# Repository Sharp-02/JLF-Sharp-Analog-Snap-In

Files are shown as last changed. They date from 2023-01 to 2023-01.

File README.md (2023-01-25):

# Sharp Analog Snap-In (SASI) Mod
### A full analog addition to the Sanwa JLF that replaces your lever's restrictor gate


# Features
- Full analog range from 0V-3.3V for Joystick X and Y
- Drop-in modification for easy installation
- Designed for fully 3D-Printable mechanical assembly
- Maintains original digital signals for both D-Pad and 
- Low profile and doesn't add much height to the stock joystick assembly
- No potentiometers that wear down with usage
- Linear hall effect sensors with sliding magnet mounts
- "Snapback Filtering" capability
- Custom PCB for footprint and consistent reproduction

# Overview
The Sharp Analog Snap-In, or SASI (pronounced "sassy"), adds analog functionality to the pre-existing Sanwa JLF lever. 

This mod was made primarily to play Smash Bros. on a fightstick. It is a component of an analog fightstick.

By measuring the position of the bottom of the lever, it outputs an analog voltage that can connect to most controller boards (boards that have 3.3V logic). 
To do this, the mod mounts magnets that move with the lever, and measures their location through a linear hall-effect sensor. 
This sensor outputs a voltage, which is amplified to match the 0V-3.3V range that most controllers use. 
*This does not use a microcontroller, and cannot be programmed.* 
A lack of programmability is desireable for cases such as tournament use or for simple implementations. 
By having no programming, the output is a direct relationship to the lever position and cannot "correct" itself automatically.
*For it's main purpose, this is just a lever that can replace a thumbstick/analog input.*

# Analog vs. Digital

The SASI mod snaps onto a Sanwa JLF lever. The Sanwa JLF is a very widespread and easily obtainable lever. 
However, this lever, like most others on the market, has only digital inputs. A digital input has only on or off states, nothing in between. 
In practice, this means that you can press up, down, left, and right, but you can't lightly move in one direction. 
This works well for most fighting games, as there is no change in movement speed depending on how far you press in a direction.

An analog system, on the other hand, does not have only discreet on/off states. 
Rather, you are able to be somewhere in the middle, maybe at 70% the maximum, or 22%, or whatever resolution your device gives you. 
For gaming, the SASI mod would allow you to gently move into a direction, or move at a specific angle.
You would want this light movement functionality in games such as Super Smash Brothers, 
where analog inputs are needed for different inputs and actions, or Mario Kart, where adjustments might be made with very slight movements.

What this is NOT is an analog-to-digital system like the programmable Magenta lever by Paradise Arcade. 
The Magenta lever acts by measuring an analog distance and setting a threshold upon which to count as a "button press". 
This mod, though it does not remove button press functionality, does not output any button press commands.

# Assembly and Installation
The mod is implemented by replacing the restrictor gate of the Sanwa JLF with a custom restrictor gate assembly. 
In this assembly are the base custom restrictor gate replacement, control PCB with the hall-effect sensors, 
slider arms that follow the lever's position, and the shroud to maintain the motion of the slider arms.

## Electronics
Components:

- DRV5053 Linear Hall Effect Sensors (x2)
- TLC2254 Op-Amp (x1)
- 0603 SMD resistors (22k, 47k, and 100)
- THT Trimpots (1k and 50k)
- 90 degree JST PH 4 position connector
- PCB

### PCB:
The PCB (printed circuit board) mounts and connects all the electronics. 
It is shaped after the Sanwa JLF's PCB that mounts the digital switches. 
On the PCB are the hall-effect sensors that measure the lever position, 
as well as potentiometers that determine the offset and voltage swing of the individual X and Y axes. 
All references to the **"front"** of the PCB refer to the side with arrows and values printed on, 
and is the side that most components solder to. The **"rear"** is the opposite side, with only the op-amp soldered on it. 
Inspect the PCB for any manufacturing errors that affect the copper traces near the outer edges and inner ring. 
Note that the PCB has SMD solder connections on both its front and rear.

Left: Front side of PCB; Right: Rear side of PCB

### Hall-Effect Sensors:
This modification uses DRV5053CAQLPG Linear Hall Effect Sensors to measure position of the lever. 

The purpose of the hall effect sensor is to measure the strength of the magnetic field and output a signal. 
The "hall effect" described makes use of the property of flowing electrons to have an induced force in the presence of a magnetic field, 
otherwise known as the Lorentz Force. The hall effect is an extrapolation of this force, wherein a current within a magnetic field 
(measured in Tesla) will "bend" as a funcion of the Lorentz force and accumulate charges in a conductor or semiconductor.

There are primarily two types of hall effect sensors seen in use today- the Hall Switch, and the Linear Hall Sensor. 
The SASI mod uses a Linear Hall Effect sensor, which outputs a voltage relative to the strength of the magnetic field. 
The sensor used is the DRV5053 whose pins when viewed from the front, from left to right, are: Vcc, GND, and Vout. 
The "CA" designation indicates that the sensor outputs a voltage of +23mV/mT. 
The "Q" designation denotes that the temperature range of the sensor is from -40 C to 125 C. 
The "LPG" designation indicates the TO-92 package type.

The DRV5053 sensors used are in a TO-92  package (through hole), ***not*** the SOT-23 package (surface mount). 
These sensors must be soldered on facing the arrows on the PCB. Once soldered, 
the outstanding legs on the opposite side of the PCB must be trimmed flush. 

As the magnet moves along the arrows in front of the sensor, the magnetic field either grows or lessens, 
depending on which pole is approaching the sensor. This means that, as the magnets are moved by the stick, 
the sensor will output a voltage depending on the position of the magnet. 
In testing, the sensor outputs a range from ~1.2V to ~2.2V. [^PCBTest]

[^PCBTest]:The PCB assembly can be tested independent of the full assembly with only a magnet. 
Orient the magnet's north and south poles along the arrow outlined in front of the sensor under testing. 
The output voltage can be measured and compared to the expected range (typically 0V - 3.3V).

### Op-Amp:
The build is tested on and utilizes the TLC2254 Op-Amp (SMD). 
This is a rail-to-rail operational amplifier and is the recommended Op-Amp to use for this mod. 

The op-amp serves the purpose of amplifying the voltage from the hall effect sensor and 
applying an offset through the trimpots as outlined below. Other op-amps *may* work, but are not guaranteed to. 

The op-amp is capable of applying a "gain" to an input voltage, which can be summarized as a direct multiplication. 
For example, a gain of 2 multiplies the input voltage by 2, and a gain of 4.3 multiplies the input voltage by 4.3. 
The SASI uses the op-amp to multiply the sensor voltage (range of ~1V) to match the voltage range expected 
by most controllers and controller boards (3.3V). This gain is altered by the relationship of resistors between 
the op-amps voltage output, voltage input, and ground. On the SASI mod, this can be tuned by turning the GAIN potetionmeters.

The op-amp is also capable of applying an "offset" to an input voltage, 
or an addition/subtraction of voltage level. As the hall-effect sensors will not output voltages starting at 0V, 
a "negative offset" must be applied to the sensor's voltage such that the final output voltage is reduced with 
the lowest output voltage of the mod being 0V. This is tuned by the OFFSET/OFF potentiometers.

The circuit below shows the diagram by which these functions can be performed. Each triangle is an amplifier. 
The TLC2254 Op-Amp contains four amplifier within its IC package.



What the op-amp ***does not do*** is read the input voltage and determine an output voltage or signal like a microcontroller would. 
Op-amps are not "programmable" in the traditional sense that microcontrollers are. 
Microcontrollers are capable of more complex interpretations of data, and can perform operations that allow for perfect inputs and timing. 
Because the op-amp works purely off the analog voltages and circuit design, it cannot be exploited in this manner.



The picture above shows the op-amps capability to amplify the blue signal and shift it up such that a 1V - 2V voltage range becomes a 0V - 3.4V voltage range.

### Trimpots:
The trimmer potentiometers, or trimpots, are a type of potentiometer that often come with multi-turn capability at varying levels of precision. 
Potentiometers are used as a variable resistor, or as a way to connect in the "middle" of a resistor. 
These properties are utilized in the op-amp circuit shown above.



These trimpots are used to alter the gain (YPOTGAIN, XPOTGAIN) and the offset (YPOTOFF, XPOTOFF) of the output voltage, 
and are labeled as such. The gain potentiometers adjust how much movement is required to register as a certain position. 
**This potentiometer has a value of 50k**. Adjust this potentiometer if the controller cannot register full motions across the X or the Y axis. 
The offest potentiometers adjust the center point of the output voltage. **This potentiometer has a value of 10k**. 
If the joystick center drifts off center *or* if the controller can register full motion in one direction but not the opposite 
(example: 100% left to 80% right), adjust this potentiometer for the required axis. Once soldered, trim the legs below flush to the PCB.

### Resistor Network:
All resistors used are 0603 SMD resistors (6mil x 3mil Surface Mount Device). 
Most of the resistors serve the purpose of setting baselines for the offset and gain on the circuit shown above. 
You will need 22k, 47k, and 100 ohm resistors.

### Snapback Filtering:
"Snapback" is a mechanical issue of the spring returning the lever *past* the centerpoint
 enough for a controller or game to register a return to neutral as an opposite direction input. 
This can be remedied through installation of a capacitor to ground, or low pass filter, 
which can reduce the signal of a sharp signal present in snapback. 

There are two locations (top and bottom) dedicated to a "snapback filtering" circuit. 
The 100 ohm resistor is integrated into this circuit. 
The remaining component is a capacitor *whose value is specific to your setup*. Most sticks will not need filtering on their SASI.

### Connector:
The JST PH connector ***is a 2.0mm pitch, not the US standard 2.54mm pitch***. 
This connector *must* be a 90 degree connector and must face out and away from the center of the PCB. 
From the front of the PCB, with the connector oriented to the right, the connector pins are as follows: 
[V+ (top), GND, Signal Y, Signal X (bottom)]. Once soldered in, trim the legs of the connector flush to the PCB.



## Mechanical Components and 3D Printing
The mechanical housing and components are designed for and around additive manufacturing processes, 
most specifically to consumer grade FDM 3D printers. Designs for machined components for low friction 
polyamide and acetate materials are planned for the future.

### Components: 

- Restrictor Gate Replacement (printed)
- Slider Arms (x2, printed)
- Linear Guide/"Hat" (printed)
- 1/8" x 1/8" x 1/2" bar magnet (x2)
- 12mm M3 screws (x4)

### Printed Part Material:
All printed parts are recommended to be printed in Nylon. All parts will undergo a sliding/rubbing motion, 
and any friction will result in less ideal movements of the lever. 
If resin printing is available, it is a good alternative. The assembly works fine with PLA/ABS as well, 
but may require more post processing and frequent application of a dry lubricant.

### Restrictor Gate Replacement:
The restrictor gate replacement is the base of the SASI. 
It houses the PCB, mounts onto the JLF, and acts as it's own restrictor gate. 
The restrictor gate's shape alters the movement of the stick and limits the shape that it can move along. 
For example, Gamecube Controllers have an *octagonal gate*, whereas the Pro Controller and Xbox Controllers have a *circle gate*. 



Which you use is simply a matter of preference. The files contain multiple gate shapes to be used. 
There are no notches in the available files [^notches] 

[^notches]: Notches are a controller modification seen in the Super Smash Brothers Melee community that allows for more specific angles to be placed in along the gate. For those interested in implementing controller notches, it may be more difficult to let the stick "lock" into a notch, as the shaft is wide and has a long area that it can slide along. 

### Slider Arms:
The Slider Arms serve the function of holding the magnets that the hall effect sensors read and, 
at the same time, wrap around the Sanwa JLF lever such that motions in the lever result in motions of the magnets. 
They feature a slot in the center into which the ***actuator*** of the lever fits into.

> picture of one slider arm on lever ; gif of sliding single arm

The lever may slide along the axis the slot opens, but the lever moves the whole part in the axis of the arms.

Two slider arms must be printed ***as mirrors of one another***. This allows them to overlap in the center. 
The 3D slider arm files given come with multiple variations. These variations are as follows:
- +BRIM- Designed with custom brims to prevent/limit warping during manufacturing on small arm sections
- +EXPANDED- Designed for materials that shrink when cooling, with an expanded center slot
- +MACHINABLE- Designed for top-down CNC machining, replacing the magnet cavity with a magnet cradle

These sliders may require post processing, as any imperfections and bumps on the surface can lead to friction and binding in the slider guide. 
This should be done with sandpaper or careful filing to flatten the sides of the slider arms.

In ***only one side of each arm***, insert a magnet and push it until the magnet cannot go any further. 
When testing, you may find that the magnet direction must be flipped. Keep this in mind before pushing in too tight or 
if no tools are available to extract the magnet from the arm (i.e. another stronger magnet). ***TEST THIS BEFORE ASSEMBLY***.
If printing in Nylon or another warp-prone material, use the Slider Arm with Brim file, which limits the warping on the small arms.

### Linear Guide:
The Linear Guide, also called the "hat", mounts above the PCB and prevents the slider arms from having any rotational motion.
The guide restricts arm movement to having only single axis motion.
The hat allows for two independent slider arms to transfer the lever angle into their own linear axis of movement.

## Assembly and Installation

Assembly and installation of the SASI mod is fairly straightforward. Very little modification to the JLF lever is required. 
Components stack on top of one another and do not require precise placement of any parts.

#### Steps:
1. Soldering and Electronics
2. Restrictor Gate and Trimming
3. Arm and Guide Hat
4. Tuning and Testing

### Step 1- Soldering and Electronics
#### 1.1- Soldering Front Components
This section is on soldering the front face of the PCB.

The front of the PCB has multiple surface mount device pads (SMDs) for resistors. Start by "tinning" every **square** pad. 
This is done by heating the pad with an iron and then applying a very small amount of solder to the pad. 
To solder a resistor in place, first identify the two solder pads that correspond to a single resistor placement. 
Prepare an 0603 SMD resistor of the proper value with metal tweezers onto the PCB, near but not on the pads, with the dark/labeled side facing up. 
Re-melt the solder on the set of pads you are soldering to by placing the iron's tip in-between them. 
Gently push the resistor into the melted solder until the resistor is in place. 
Hold the resistors in place as you remove the iron. 
Repeat this process for every resistor.

Next, it is best to solder the JST-PH connector.
Insert the connector with the connection port facing outward and away from the center.
Flip the PCB and hold or place the connector such that a solder can be performed on the rear side.
Solder the pins down, making sure that the connector is solidly in place and not tilted.

After this, solder the trimmer potentiometers.
Take care that each resistor put in is the correct value. 
Bend the legs below such that the trimpots will not move, and flip the board upside-down.
Solder each leg to the through hole.
Trim the legs flush to the bottom of the PCB.

For soldering the hall effect sensors, a similar approach can be taken to that of the potentiometers.
Make sure to mound the hall effect sensors such that the small side faces towards the arrow near it.
Insert the hall effect sensor *all the way*. When inserted, there should only be ~1mm of the legs above the PCB.
Once again, bend the legs below so that the hall effect sensor does not move and solder them in place.

*If you need to solder a capacitor*, perform the same steps as the hall effect sensor soldering.
This, however, is not a snapback elimination guide. 
The process to analyze snapback, though, is the same as with a thumbstick.

#### 1.2 Soldering Rear Component

On the back of the lever are the op-amp pads. The TLC2254 op-amp is the only op amp used, and is the only component on the back of the PCB.
Observe and make note of the small half-circle mark at the top of the outline.
The op-amp component will have a marking on one of its sides. This marking can be a divot, dot, or line.

  

Start by tinning the solder pads in a similar way to the SMD resistors outlined above.
Do not let any of the solder bridge from pad to pad. There should be very little solder on each pad.
Use tweezers to position the op-amp such that each leg is over every pad.
Remelt one corner pad with the iron and gently press the op-amp into place.
Let the corner pad cool, and then repeat the process with the opposite corner pad.
If you are unhappy with the positioning, adjust the two corners until you are satisfied.
Remelt the solder at each solder pad, letting it flow and cover the leg it is on.
The time at each leg should be minimal, and should not take a long time.

#### 1.3 Making a connector

To make a connector to the PCB, prepare four wires of equal length.
The recommended wire and gauge to use is 30AWG stranded wire.
This allows for flexing and movement of the wires with less wear.
Strip one end of each wire and crimp a female JST-PH connector onto the end.
Make sure the inner crimp clamps onto the stripped wire and the outer crimp clamps down the silicone sheathing.
Insert this wire into a female JST-PH connector. 
Repeat this process with the other three wires.

### Step 2- Restrictor Gate and Trimming
#### 2.1 Gate Replacement and Trimming
Remove the original restrictor gate from the Sanwa JLF. This is typically a clear part.
Snap on the SASI Restrictor Gate Replacement.
Mark the oval protrusions at the height of the restrictor gate replacement.
Remove the Restrictor Gate Replacement and cut/trim the oval protrusions at the mark.
**THIS STEP IS CRUCIAL:**
Attach the Gate Replacement and *verify that the oval parts are flush or below the surface of the replacement gate.*

#### 2.2 Replacing the Gate pt. 2
When viewing the bottom of the JLF, ensure that the 5 pins from the JLF's microswitch board face outward from the top right of the board.

The orientation of the restrictor gate is crucial. Identify the eccentric rectangular hole in the restrictor gate.
Make sure that this hole is on the ***left*** side of the JLF, opposite from the 5 pins.

From here, place the soldered PCB into the SASI Restrictor Gate Replacement. 
The op-amp should be facing down and will fit into the rectangular hole, 
while the 4-pin connector faces in the same direction as the JLF's 5 pin connector.

### Step 3- Arm and Slider Guide/"Hat"
#### 3.1 Post Processing
Due to the motions taken by 3D printers, some corners and edges may "blob" outwards and create a wavy surface.
Take each slider arm and sand or file the sides of the arms such that they are straight and smooth.
Observe if the same must be done for the Slider Guide. If similar blobs or wavy patterns are seen, file and sand until smooth.
Do not over-sand, as the looser this tolerance is the less precision there will be from the SASI mod.

#### 3.2 Magnet Insertion
On each arm, identify the hole that will be snug to the bar magnet, but not too tight to insert/extract.
The ability to extract is crucial, as mistakes may be made that require removal of the magnet.
Once identified, insert the magnet fully, but ***do not seal the hole***.

#### 3.3 Slider Testing
Orient the arms on the PCB such that the magnets are in front of the two hall effect sensors.
Gently place the Slider Guide over the slider arms, letting the slider arms slot into the slider guide. 
Remove the Slider Guide and Slider Arms together and move the arms individually to see if there are any binding areas.
If there is no binding and low friction, you are ready for the next step.
If there is binding, maintain the orientation of the arms, but move the slider guide to a new angle until you find the smoothest motion.

#### 3.4 Final Assembly
Replace the SASI Slider Guide and Arms over the PCB and around the lever.
Pinch down firmly at each corner and screw in an M3 screw. Repeat this at every corner.
Finally, feel if the stick is smooth from above. If it is not, return to previous steps to reduce binding.

### Step 4- Tuning and Testing
Once assembled, connect the analog X and analog Y outputs from the stick to the board you are using, alongside the ground and 3.3V connection. 
The connection method varies from board to board. Check with the board manufacturer for the recommended connection method to analog stick inputs.

It is recommended to test the stick without installing it in a panel, so that changes can be easily made.

This can be tested either through a joystick viewer found online or in software, 
or through an oscilloscope by measuring the voltage output. The process remains the same.

Only test one axis at a time. Start by moving the stick fully in one direction, then fully in the other.
If the stick shows that it is moving in reverse, extract the magnet under testing, reverse its orientation, and test again.

Next, make note of two different parameters. The first to observe is the "center point" of the output.
On a joystick tester, it is as simple as checking if the joystick rests at the middle of the axis you are testing.
On an oscilloscope, the "middle" is a level of 1.67V (or 2.5V if you reference a 5V supply). 
If the joystick isn't centered, turn the axis offset potentiometer (right side)such that the signal becomes centered.

Then, once again, move the joystick all the way in both directions of the axis you are testing. 
If the joystick does not reach the maximum, hold the joystick at the maximum and turn the axis gain potentiometer until it reaches it's maximum. 
Once this threshold is hit, hold the joystick in the opposite direction and observe if it reaches the opposite maximum. 
If it does, still read the next paragraph. If it does not, release the joystick and repeat the steps of the previous paragraph.

This paragraph addresses the "outer deadzone", or the range at which the maximum is reached.
Some may prefer that the maximum is reached only at the gate, while some may prefer that the maximum is reached before then.
Treat this section as a sensitivity section.
Start by identifying what your preference is.
Then, ***slowly*** move the stick, observing both the physical stick position ***and*** the software stick position.
If you are not at the measured position that you want, turn the gain potentiometer such that the stick moves in the direction of the desired position.
During this process, constantly check if the joystick's resting position is truly the center of the axis.

After all this, repeat the tuning process on the second axis.

The final and most important step for testing is 
### Play a game!!!
Boot up Dolphin and play some Melee, or see how the joystick feels in Rocket League. Whatever you made this stick for, use it!
This is the truest test you can find, and will very quickly identify any problems you have with the SASI JLF mod.

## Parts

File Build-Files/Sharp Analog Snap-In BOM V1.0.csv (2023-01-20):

Part Name | Part Number | Description | Value | Size | Quantity | Cost Per | Shipping Estimate | Cost Sum | Total Sum | Part Link | Section Sum
Electronics
22k Resistor |  | 0603 SMD | 22k | 0603 | 2 | $0.10 |  | $0.20 | $0.20 |  | $19.50
47k Resistor |  | 0603 SMD | 47k | 0603 | 2 | $0.10 |  | $0.20 | $0.20
100 Resistor |  | 0603 SMD | 100 | 0603 | 2 | $0.10 |  | $0.20 | $0.20
1k Trimpot |  | 3 Pin Trimpot, 10mil pitch | 1k | RTRIMT93YA | 2 | $1.25 |  | $2.50 | $2.50 | https://www.digikey.com/en/products/detail/bourns-inc/PV36W103C01B00/666502
50k Trimpot |  | 3 Pin Trimpot, 10mil pitch | 50k | RTRIMT93YA | 2 | $1.25 |  | $2.50 | $2.50 | https://www.digikey.com/en/products/detail/bourns-inc/PV36W103C01B00/666502
Hall Effect Sensor | DRV5053CAQLPG | Linear Hall Sensor- Through Hole |  | TO-92 | 2 | $1.50 |  | $3.00 | $3.00 | https://www.digikey.com/en/products/detail/texas-instruments/TLC2254CDR/276943
R2R Op-Amp | TLC2254CDR | Rail to Rail Quad Op Amp |  | SOIC-14 | 1 | $3.00 | $2.00 | $3.00 | $5.00 | https://www.digikey.com/en/products/detail/texas-instruments/DRV5053CAQLPGM/5177930
PCB |  | Custom Built PCB |  |  | 1 | $2.00 | $2.00 | $2.00 | $4.00
JST-PH Connector |  | JST-PH 4 Pin, 90 Degrees | 90 Deg | PH | 1 | $0.90 | $0.50 | $0.90 | $1.40
Wires |  | 30 AWG Stranded |  | 12 in. | 4 |  | $0.50 | $0.00 | $0.50
Mechanical Components
Bar Magnet | B228 | K&J Magnetics; Length Magnetized | N42 | 1/8" x 1/8" x 1/2" | 2 | $0.60 | $5.00 | $1.20 | $6.20 | https://www.kjmagnetics.com/proddetail.asp?prod=B228 | $7.90
M3 Screws |  | M3 x 12mm screws | M3 | 12mm | 4 | $0.10 | $0.50 | $0.40 | $0.90
3DP Gate (P) |  | Printed PLA Replacement Gate |  |  | 1 | $0.20 | $0.00 | $0.20 | $0.20 | https://github.com/Sharp-02/JLF-Sharp-Analog-Snap-In/tree/main/Build-Files/3DPrint-STLs
3DP Arm (P) |  | Printed PLA Slider Arm |  |  | 2 | $0.20 | $0.00 | $0.40 | $0.40 | https://github.com/Sharp-02/JLF-Sharp-Analog-Snap-In/tree/main/Build-Files/3DPrint-STLs
3DP Guide (P) |  | Printed PLA Slider Guide |  |  | 1 | $0.20 | $0.00 | $0.20 | $0.20 | https://github.com/Sharp-02/JLF-Sharp-Analog-Snap-In/tree/main/Build-Files/3DPrint-STLs
3DP Gate (N) |  | Printed Nylon Replacement Gate |  |  | 1 | $2.00 | $0.00 | $2.00 | $2.00 | https://github.com/Sharp-02/JLF-Sharp-Analog-Snap-In/tree/main/Build-Files/3DPrint-STLs | $14.10
3DP Arm (N) |  | Printed Nylon Slider Arm |  |  | 2 | $1.50 | $0.00 | $3.00 | $3.00 | https://github.com/Sharp-02/JLF-Sharp-Analog-Snap-In/tree/main/Build-Files/3DPrint-STLs
3DP Guide (N) |  | Printed Nylon Slider Guide |  |  | 1 | $2.00 | $0.00 | $2.00 | $2.00 | https://github.com/Sharp-02/JLF-Sharp-Analog-Snap-In/tree/main/Build-Files/3DPrint-STLs
Sanwa JLF Lever | JLF-TP-8YT | Sanwa-Denshi JLF Lever |  |  | 1 | $25.00 | $2.00 | $25.00 | $27.00 | https://focusattack.com/sanwa-jlf-tp-8yt-joystick/
 |  |  |  |  |  |  | Mod Sum (PLA) | $16.90 | $27.40

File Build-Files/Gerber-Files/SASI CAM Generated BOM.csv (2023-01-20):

Qty | Value | Device | Package | Parts | Description | COPYRIGHT | DIGI-KEY_PART_NUMBER_1 | DIGI-KEY_PART_NUMBER_2 | DIGI-KEY_PART_NUMBER_3 | MANUFACTURER_PART_NUMBER | MFR_NAME | POPULARITY | PROD_ID | SF_ID | SPICEMODEL | SPICEPREFIX | SPICEPREFIXL
2 |  | C-US025-024X044 | C025-024X044 | X_CF, Y_CF | CAPACITOR, American symbol |  |  |  |  |  |  | 17 |  |  |  | C
1 |  | CONN_04JST-PTH | JST-4-PTH | J1 | Multi connection point. Often used as Generic Header-pin footprint for 0.1 inch spaced/style header connections |  |  |  |  |  |  |  | WIRE-13531 | PRT-09916
2 | 100 | R-US_R0603 | R0603 | X_RF, Y_RF | RESISTOR, American symbol |  |  |  |  |  |  | 77 |  |  |  | R
2 | 1k | R-TRIMMT93YA | RTRIMT93YA | XPOTOFF, YPOTOFF | Trimm resistor |  |  |  |  |  |  | 2 |  |  | X |  | POT
2 | 22k | R-US_R0603 | R0603 | X_R1, Y_R1 | RESISTOR, American symbol |  |  |  |  |  |  | 77 |  |  |  | R
2 | 47k | R-US_R0603 | R0603 | X_R2, Y_R2 | RESISTOR, American symbol |  |  |  |  |  |  | 77 |  |  |  | R
2 | 50k | R-TRIMMT93YA | RTRIMT93YA | XPOTGAIN, YPOTGAIN | Trimm resistor |  |  |  |  |  |  | 2 |  |  | X |  | POT
2 | DRV5053CAQLPGMPACK2 | DRV5053CAQLPGMPACK2 | LPG3_TEX_OFFSET | DRV_X, DRV_Y
1 | TLC2254CDR | TLC2254CDR | D14 | QUAD_OP_AMP |  | Copyright (C) 2022 Ultra Librarian. All rights reserved. | 296-1300-1-ND | 296-1300-2-ND | 296-1300-6-ND | TLC2254CDR | Texas Instruments

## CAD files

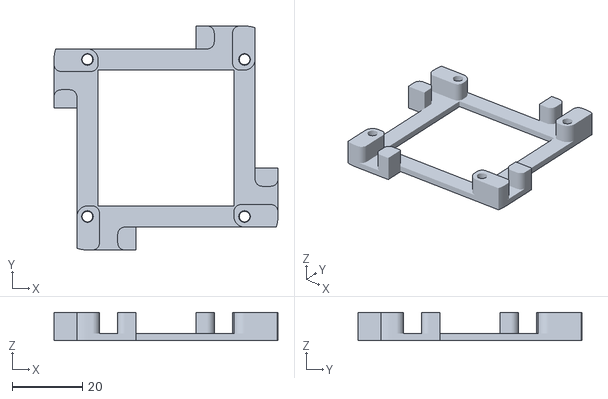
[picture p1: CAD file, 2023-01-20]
Build-Files/3DPrint-STLs/SASI Linear Guide (Hat).stl
63.6 x 63.6 x 8.00

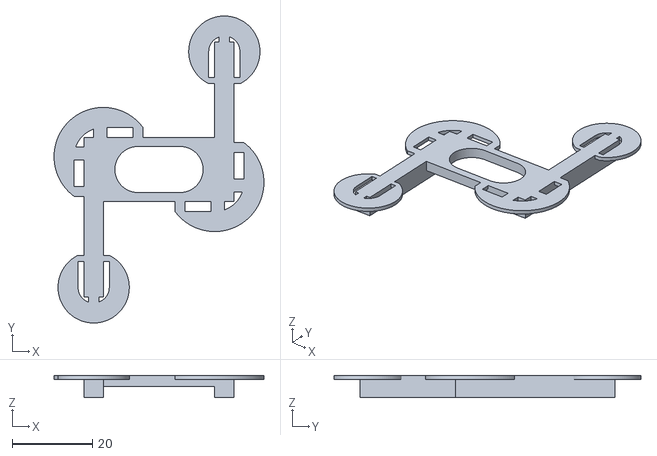
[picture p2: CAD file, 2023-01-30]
Build-Files/3DPrint-STLs/Slider-Arm-Alternatives/SASI Slider Arm MACHINABLE EXPANDED BRIM.stl
52.4 x 76.6 x 5.50

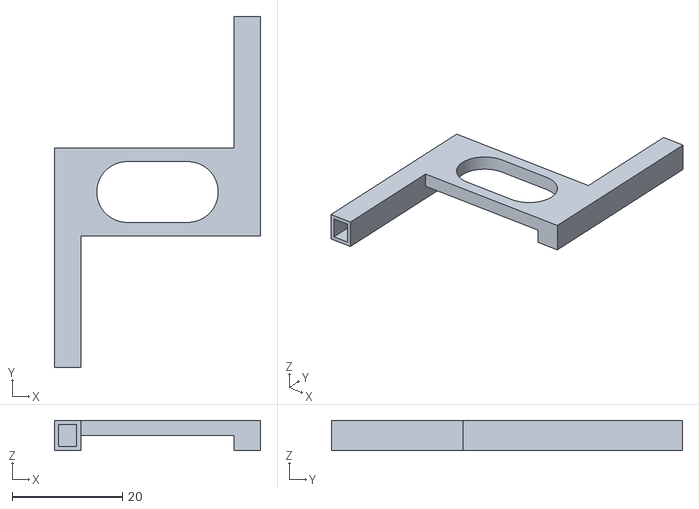
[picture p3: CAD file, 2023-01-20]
Build-Files/3DPrint-STLs/SASI Slider Arm.stl
37.4 x 63.6 x 5.50

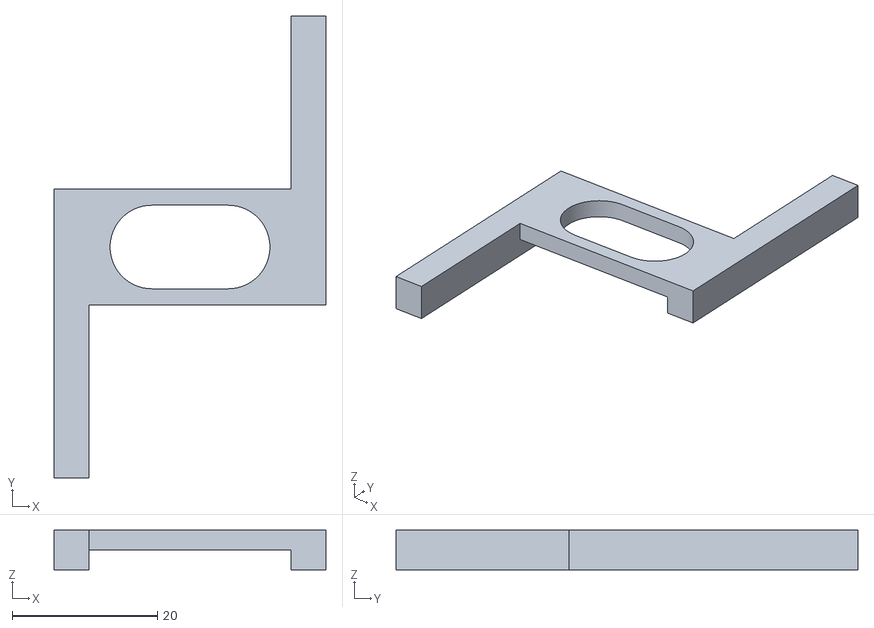
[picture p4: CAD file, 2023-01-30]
Build-Files/3DPrint-STLs/Slider-Arm-Alternatives/SASI Slider Arm MACHINABLE EXPANDED.stl
37.4 x 63.6 x 5.50

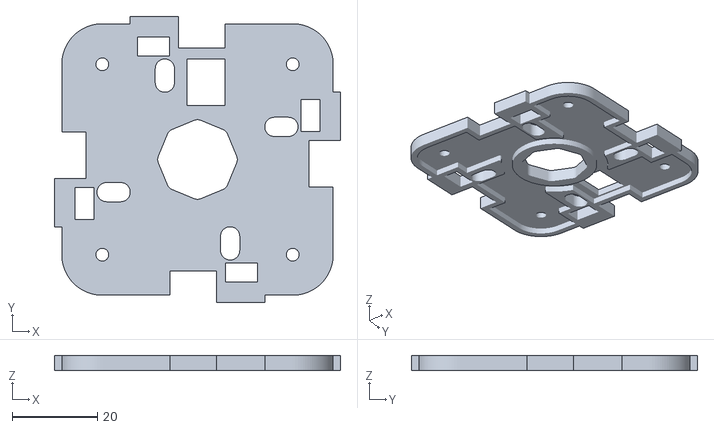
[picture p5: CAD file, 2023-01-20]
Build-Files/3DPrint-STLs/SASI Restrictor Gate- 19mm Gate.stl
67.0 x 67.0 x 3.50

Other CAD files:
Build-Files/3DPrint-STLs/SASI Slider Arm MIRRORED.stl

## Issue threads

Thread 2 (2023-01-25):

Specific details for parts missing in README

HiramSilvey, 2023-01-25:
Hi, I noticed in the README the parts list mentions:
```
VALUE x VALUE bar magnet (x2)
LENGTH M3 screws (x4)
```
Were `VALUE` and `LENGTH` meant to be replaced with more specific information? If not, do you have specific magnets or screws that you could recommend purchasing if building independently?

Thanks so much,
Hiram

Sharp-02, 2023-01-28:
Hey, sorry I missed fixing some stuff in the README, and I still have a few things left to fill in.
The bar magnets are to be 1/8" x 1/8" x 1/2" bar magnets, though I believe cylindrical magnets might work too.
The M3 screws should be 12mm

Closed 2023-01-28.

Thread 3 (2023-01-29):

Slider arm STLs

HiramSilvey, 2023-01-29:
Hi Sharp,

I notice in the README you mentioned 3 variations on the slider arm STL files. However, when looking at the STLs themselves, I only see 2 files for the slider arms: "SASI Slider Arm" and "SASI Slider Arm MIRRORED."

Should the variations mentioned in the README be present as well, or did I misunderstand?

Thanks

Sharp-02, 2023-01-30:
They should be in the STLs folder now! I missed uploading them when updating the README

Closed 2023-02-25.

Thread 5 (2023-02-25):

Screws don't hold enclosure together

HiramSilvey, 2023-02-25:
I ordered 3d printed nylon parts online rather than using a home printer.

When I insert the m3 screws to lock the pieces together, though, the screw holes are roughly the same size as the screw so the screw doesn't actually bite into anything. As a result, the entire 3d printed enclosure isn't secured.

I fixed this by purchasing slightly longer m3 screws and some m3 nuts to place on the other side of the 3d printed parts. This works well, but I figured I'd mention the issue as a potential improvement for the future.

Having a 3d printed hex nut pocket on the underside of the enclosure would be ideal, imo.

acendan, 2023-04-01:
I'm having the same issue. The M3 screws don't fit and are too loose for the printed holes. Time to order some threaded inserts...

Closed 2024-04-02.

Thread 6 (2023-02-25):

Additional debug documentation?

HiramSilvey, 2023-02-25:
I successfully soldered and assembled a complete SASI, but the sensor readings ended up being completely out of whack. :(

For example, the joystick believes it's being pressed fully to the right when it's in the neutral position. Adjusting the trimpots to re-center it only moves it slightly over before it's unable to move it anymore.

The Y axis is extremely broken as well for some reason. Pressing up moves the output at a 45 degree angle north west. Pressing down moves the output straight east.

The X axis is wonky as well. Left moves the output north west and right moves it straight east. Left additionally continues moving independently east after physically holding it in the left-most position.

Adjusting the trimpots in general hasn't been able to fix these issues.

Is there additional debug documentation that could be used for a case like this? What are some good troubleshooting steps that could be followed? Does this just sound like bad soldering, or is this a common occurrence with a known solution?

All components were purchased according to the README specification, but perhaps the exact items you've successfully built versions with would be more helpful? It seems easier to pinpoint issues when there's at least guarantee that _all_ components are identical to a working version.

Closed 2024-04-02.

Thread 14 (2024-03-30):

Toggle Switch for changing mode.

vegedb, 2024-03-30:
Is there a way to disable analog and use dpad with a push of a button?
I've read through the readme, can't seem to find a way to disable analog mode with a toggle switch.

Sharp-02, 2024-03-30:
> Is there a way to disable analog and use dpad with a push of a button?
> I've read through the readme, can't seem to find a way to disable analog mode with a toggle switch.

The all v1 SASIs are incapable of standalone dpad functionality. They are fully analog devices. That being said, an external circuit can certainly be made to feature button switch dpad functionality.

vegedb, 2024-04-22:
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

I'm confused, does your mod disable the microswitches pins for dpad (L,R,U,D,GND)?
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

If not, a simple 4PDT switch can be used to turn on/off dpad.

Sharp-02, 2024-05-03:
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

It does not. However there is no native functionality to disable the analog features. Disconnecting the SASI would likely result in the control board registering a -X,-Y input.

If you want to switch the DPAD on and off, you only need a SPST switch to open and close the ground line. However, if you would like to toggle between the two, you need more complex circuitry.

Closed 2024-03-30.

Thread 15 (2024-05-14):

X axis pin slow to reach Vcc

mtat12, 2024-05-14:
Over the past few months I've sourced the PCB and parts for this according to your instructions as close as possible, but I'm having an issue with the signal coming out of the SASI mod board for the X axis. When the magnet passes over the voltage reaches ~2.9V quickly, but slows to a crawl the rest of the way up to Vcc (over ~5 seconds). Using controller testers and direct measurement, I noticed this regardless of the X axis potentiometer settings. While I haven't noticed this in-game for the Y axis, it appears to function as normal on controller joystick tests.

I've made sure to purchase exactly what was specified (at time of order) with the exception of the DRV5053. The specific "A3" part appeared to be out of stock where I was ordering from, so I purchased the nearly identical (as far as I can tell) DRV5053**CA**QDBZR [datasheet here](https://www.ti.com/lit/ds/symlink/drv5053.pdf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).

I see that since I ordered this the recommended hall effect sensor has been changed to a DRV5055, is my issue potentially related to this? If so is +25mV/mT still the correct spec? i.e. is the [DRV5055A3QDBZT](https://www.digikey.ca/en/products/detail/texas-instruments/DRV5055A3QDBZT/8343717) suitable? Your guide still mentions the 5053 for the section with component specifics.

It's just enough that I'm unable to get SSBU to recognize sudden right inputs for forward smashes or running, so I'd appreciate any help you can provide. I really enjoy this mod by the way, thank you so much for making this!

Sharp-02, 2024-08-13:
Connect the supply voltage to 5V and tune down the gain respectively. The issue stems from the Op-Amp's upper rail capabilities. This will be fixed in future revisions.

Closed 2024-08-13.

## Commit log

2023-01-20 Added V1.0 STL Files
    [SASI Linear Guide (Hat).stl, SASI Restrictor Gate- 19mm Gate.stl, SASI Slider Arm MIRRORED.stl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]
2023-01-20 Created Gerber-Files Folder
2023-01-20 Added V1.0 Gerber Files
2023-01-20 Added Gerber BOMs V1.0
    [SASI CAM Generated BOM.csv, SASI CAM Generated BOM.xlsx]
2023-01-20 Added BOM
    [Sharp Analog Snap-In BOM V1.0.csv, Sharp Analog Snap-In BOM V1.0.xlsx]
2023-01-21 Replaced Gerber Files
    Replacing Gerber Files with marked PCB
2023-01-21 Add Marked Gerber Files
2023-01-30 Slider Arm Alternatives v1.0 Added
2023-01-30 Slider Arm Variation ME Added
    [SASI Slider Arm MACHINABLE EXPANDED.stl]
2023-01-30 Slider Arm Variation MEB Added
    [SASI Slider Arm MACHINABLE EXPANDED BRIM.stl]
